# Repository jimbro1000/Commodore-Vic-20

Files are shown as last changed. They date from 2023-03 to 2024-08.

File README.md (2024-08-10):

# Commodore VIC-20 Schematic and PCB for assembly 250403

This repository contains KiCad schematics and "rough" PCB layout for the
cost reduced VIC-20, assembly #250403.

Originally hard forked from <https://github.com/StormTrooper/Commodore-Vic-20>
(this does not appear to be maintained).

The schematic for the Commodore VIC-20 (251027-01 Rev D) was taken from the
schematics on zimmers.net with extra detail from the "Vic-20 friendly computer
technical manual" and converted into KiCad (Version 8).

Additionally includes some KiCad footprints and symbols for the custom components.

## State

The schematics are complete and 95% of the PCB layout is done but it is not
complete. The power supply section of the board is mostly unfinished, and
accurate footprints for the large inductor, power switch and bridge rectifier are
needed.

## Notes

This is a WIP as the documentation and detail on the actual PCB are far from
clear and require some deciphering.

The power management section of the board in particular is unfinished.

The PCB design, while true to the original, is not intended for fabrication.
Instead the board has been reconstructed for the purpose of diagnosing faults
on original Commodore boards. The overall board dimensions are accurate but
the positioning of the different ports are approximations based on the rather
distorted board scans in the technical manual.

## KiCad thumbnail of schematic and pcb

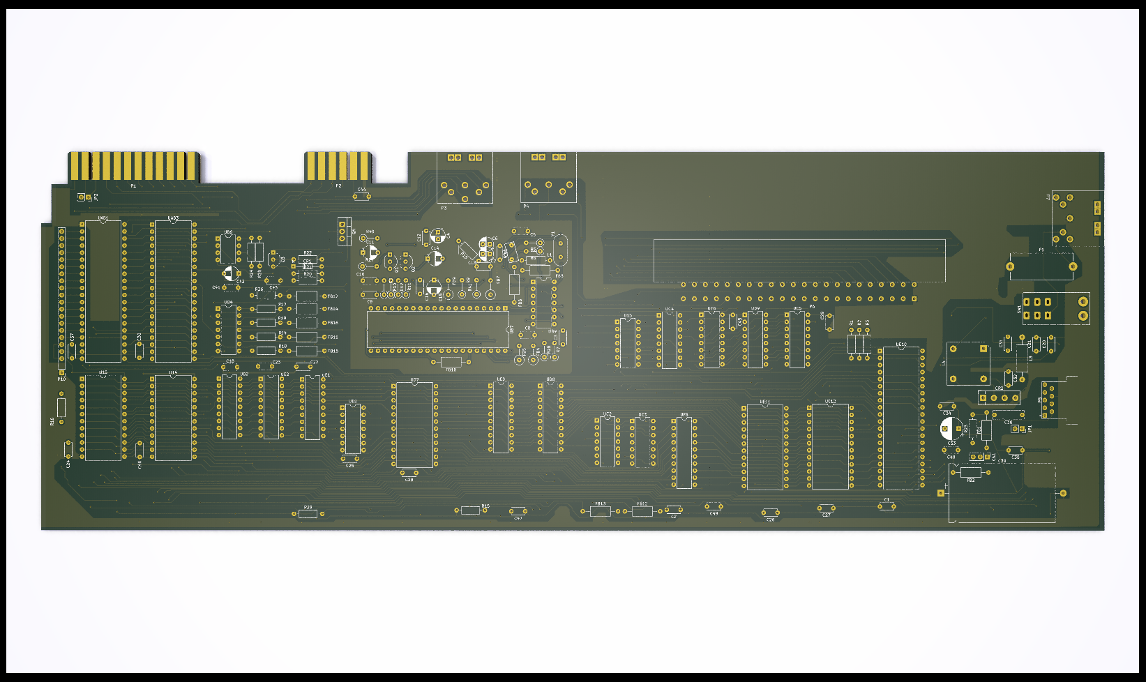
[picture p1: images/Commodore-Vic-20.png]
render of PCB


cad view of schematics

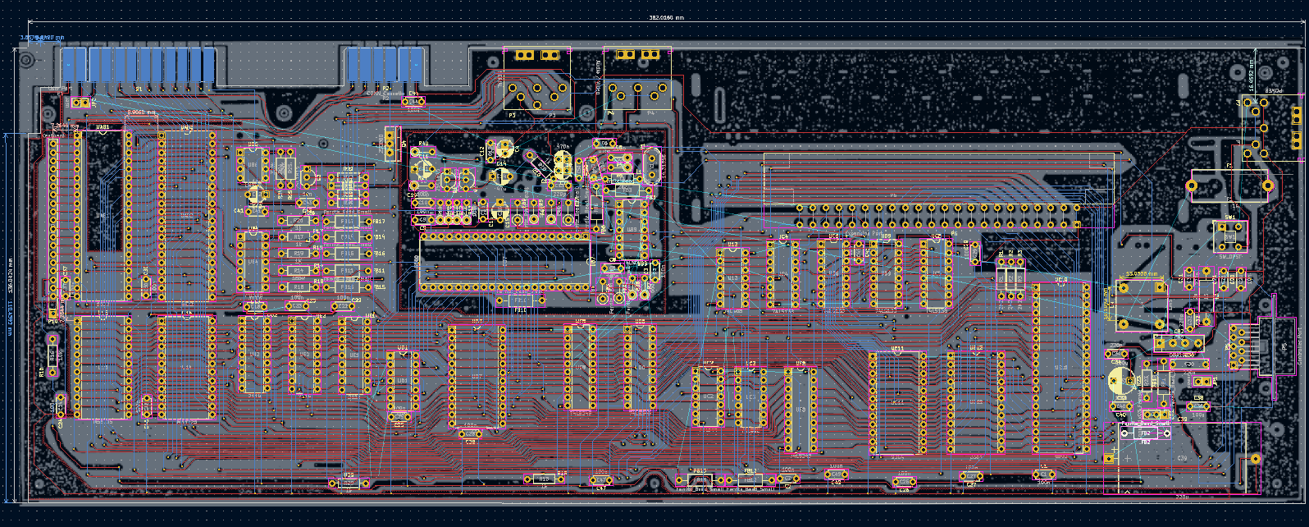
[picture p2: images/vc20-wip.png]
cad view of pcb


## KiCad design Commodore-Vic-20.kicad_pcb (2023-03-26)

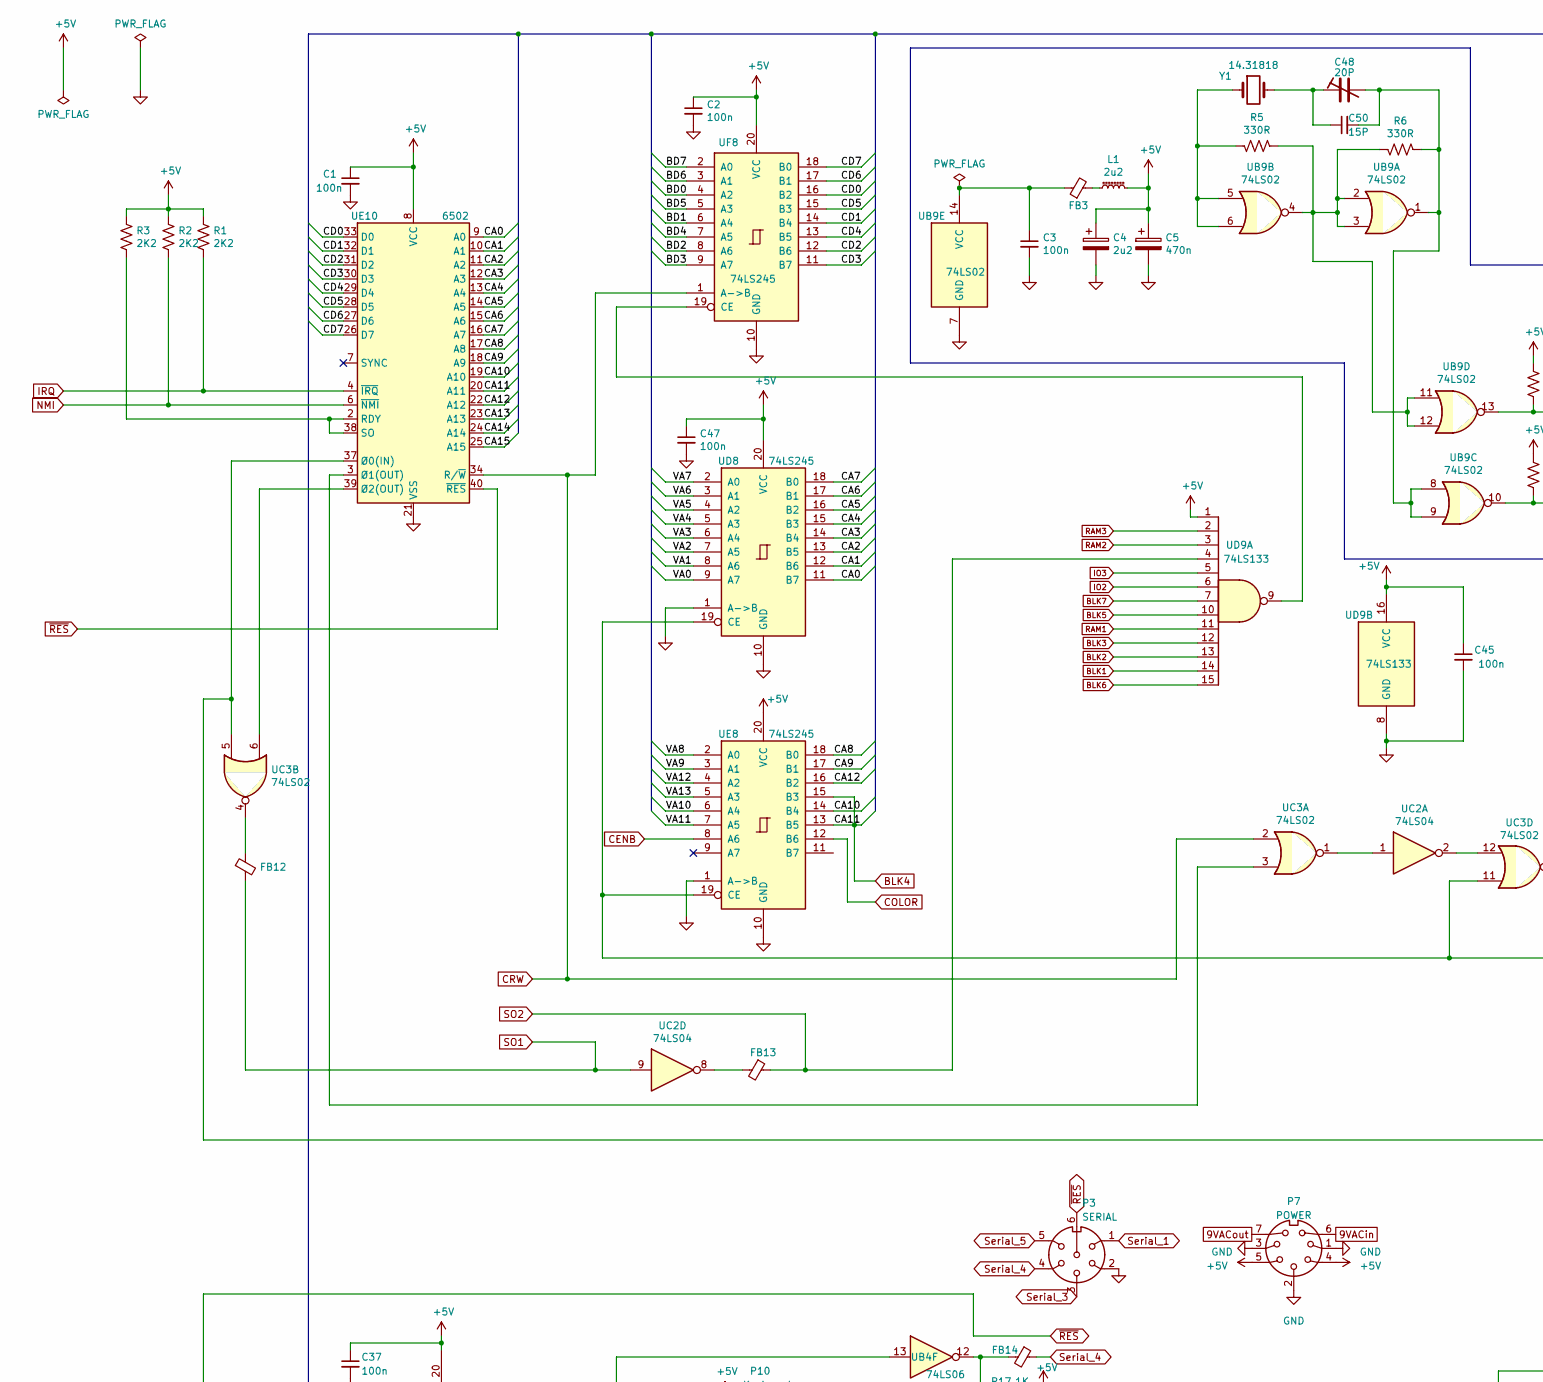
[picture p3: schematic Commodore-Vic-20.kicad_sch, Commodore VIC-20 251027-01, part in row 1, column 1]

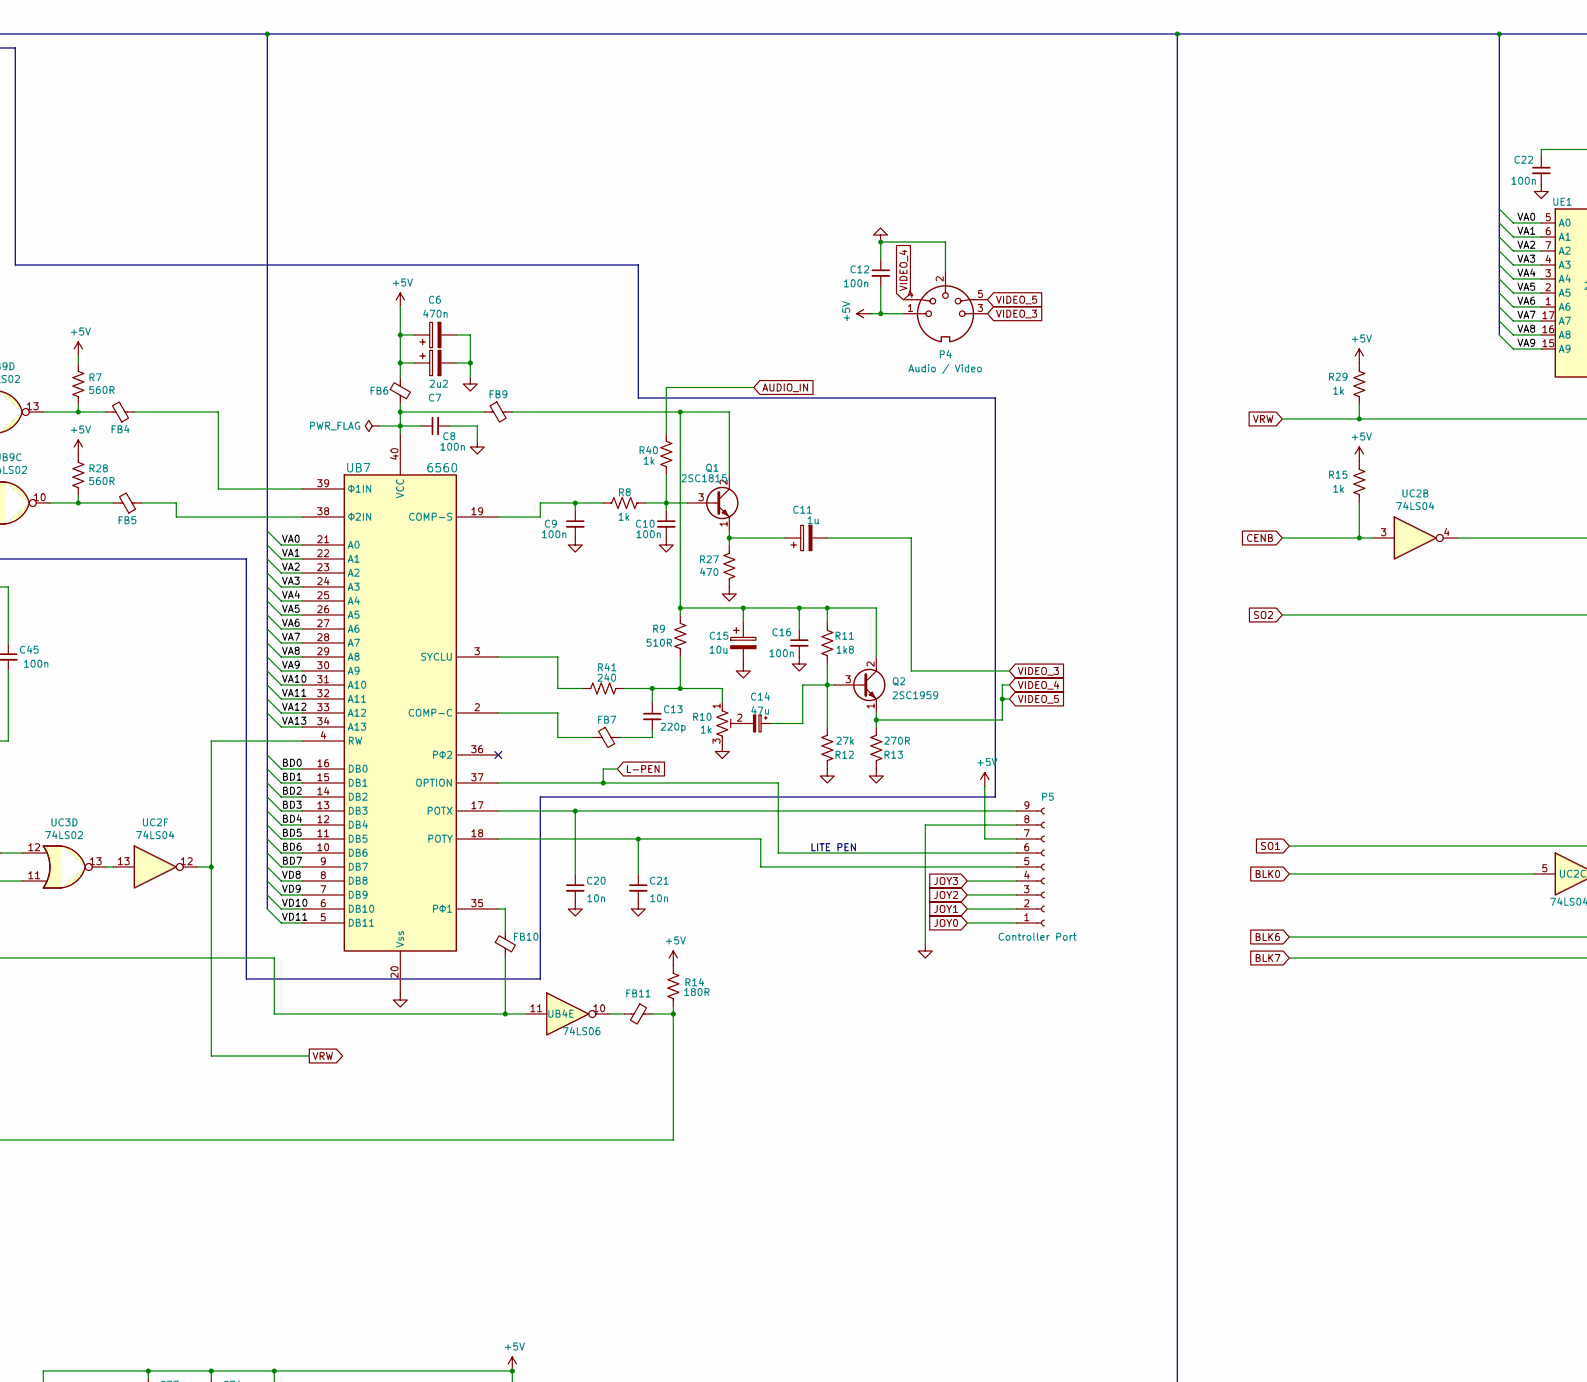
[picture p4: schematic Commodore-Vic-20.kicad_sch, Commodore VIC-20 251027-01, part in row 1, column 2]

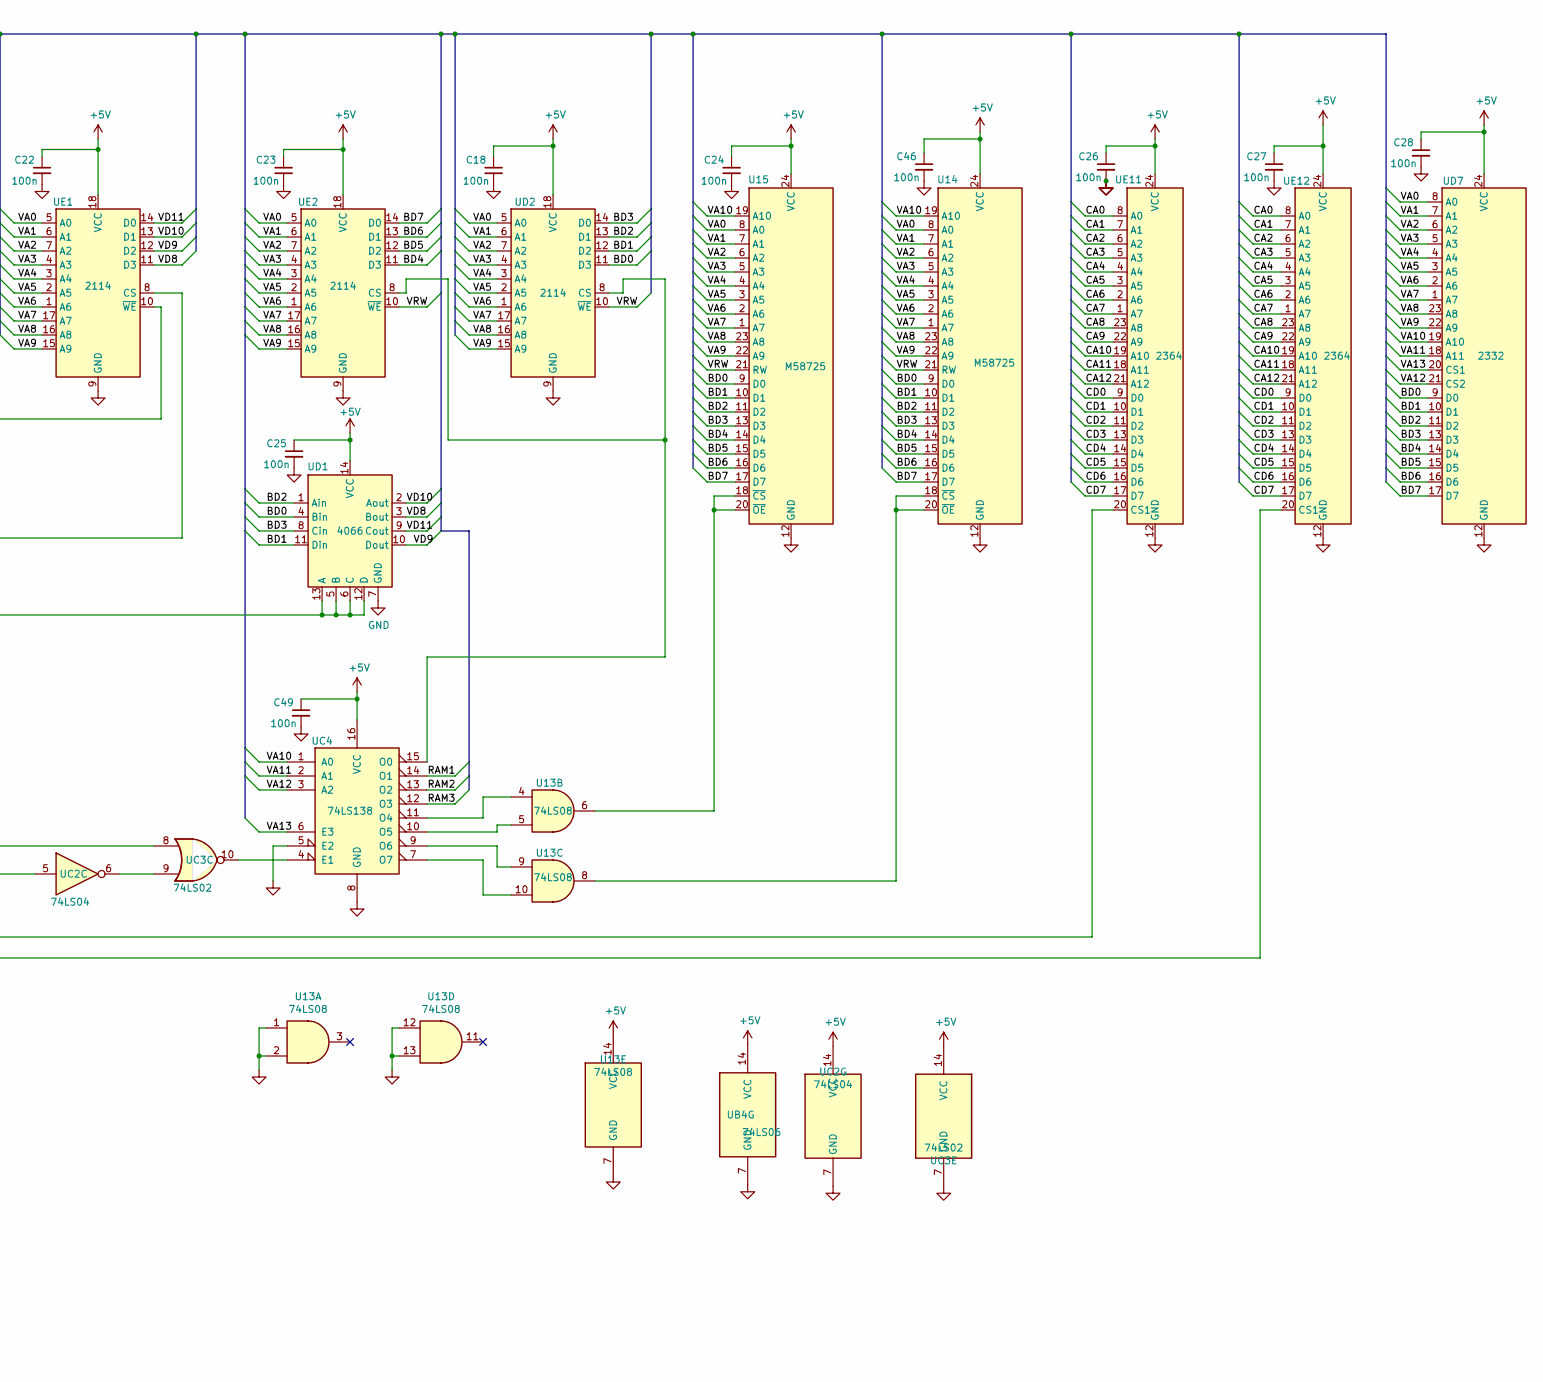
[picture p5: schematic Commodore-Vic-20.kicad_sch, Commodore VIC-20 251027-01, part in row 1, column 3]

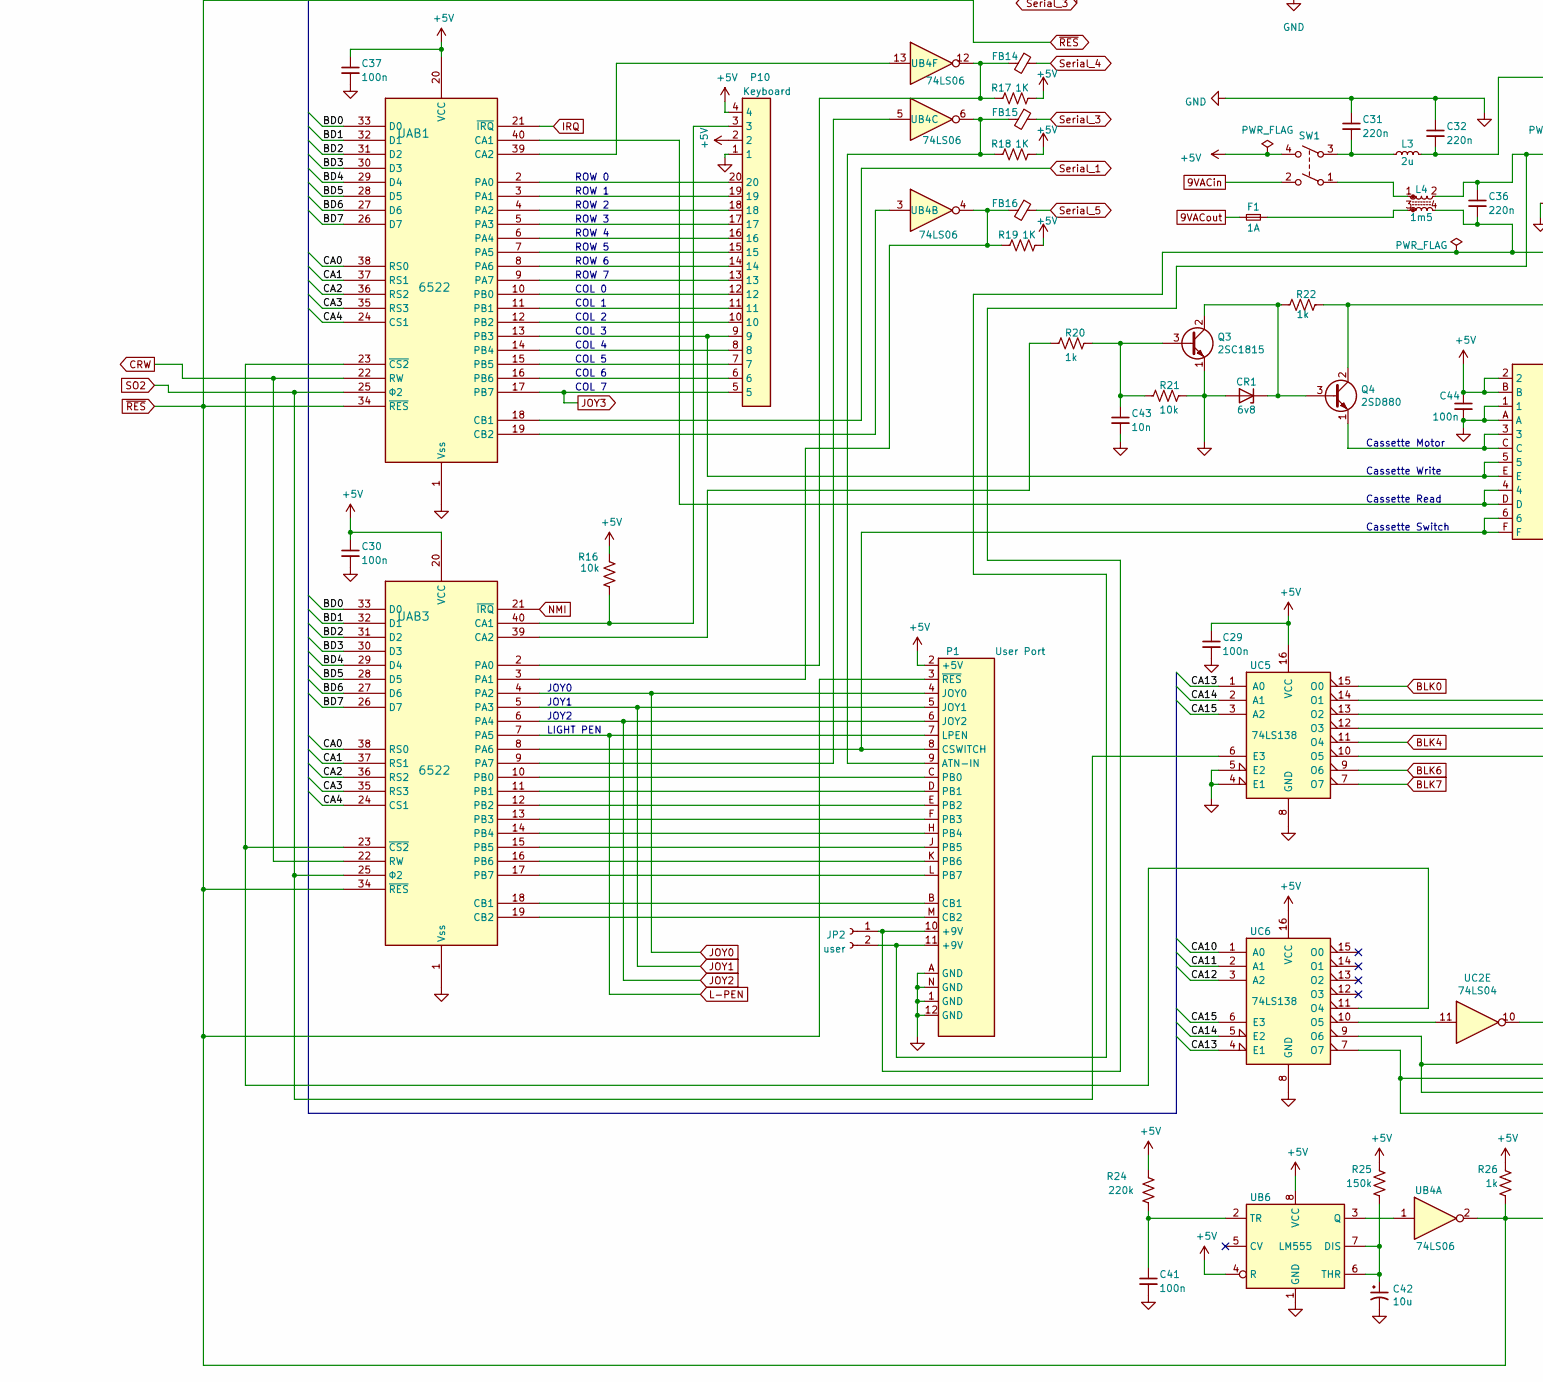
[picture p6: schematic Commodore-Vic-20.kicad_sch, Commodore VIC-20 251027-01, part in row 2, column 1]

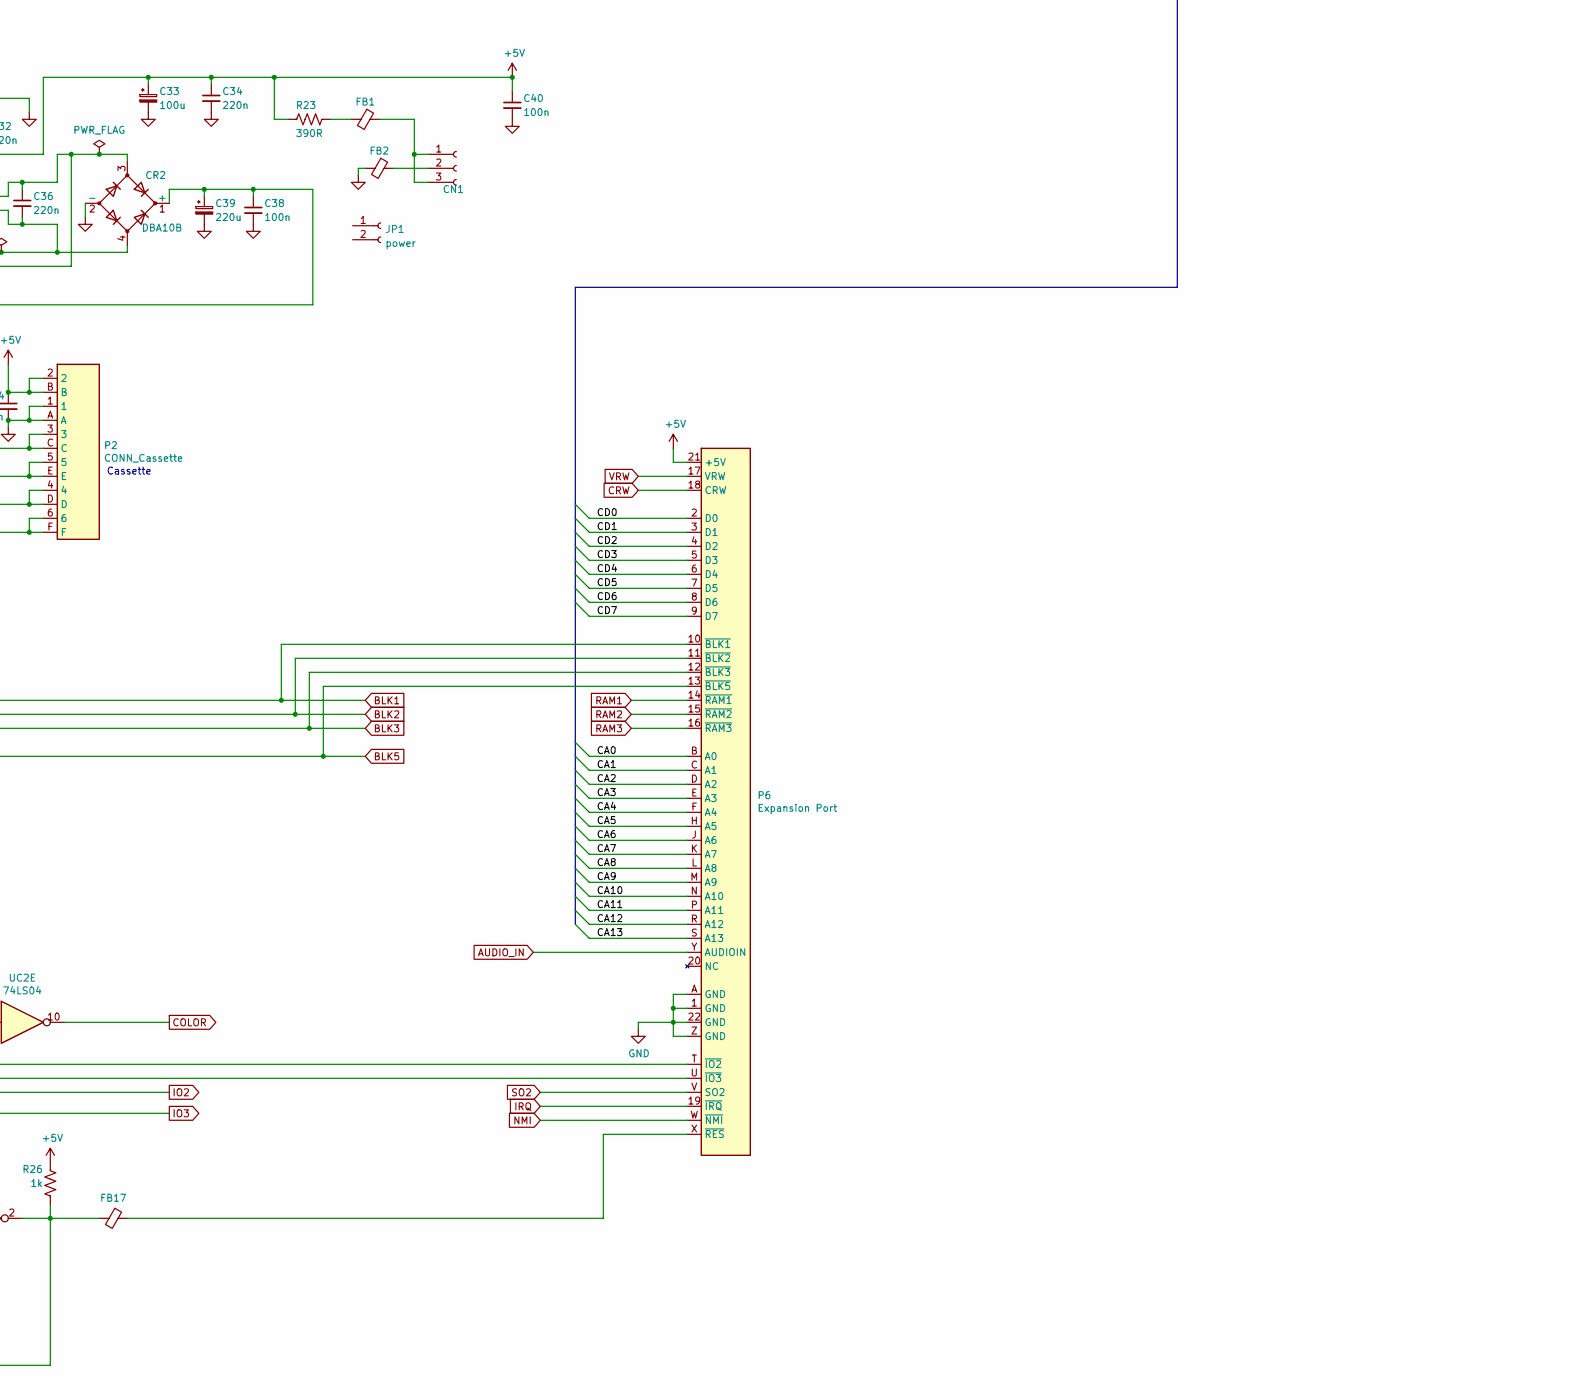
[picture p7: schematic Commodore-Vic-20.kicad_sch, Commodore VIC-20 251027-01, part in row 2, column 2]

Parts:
C1, C2, C3, C8, C9, C10, C12, C16, C18, C22, C23, C24, C25, C26, C27, C28, C29, C30, C37, C38, C40, C41, C44, C45, C46, C47, C49: 100n; C_Disc_D4.7mm_W2.5mm_P5.00mm
C4, C7: 2u2; CP_Radial_D5.0mm_P2.50mm
C5: 470n; C_Disc_D4.7mm_W2.5mm_P5.00mm
C6: 470n; CP_Radial_D5.0mm_P2.50mm
C11: 1u; CP_Radial_D5.0mm_P5.0mm
C13: 220p; C_Disc_D4.7mm_W2.5mm_P5.00mm
C14: 47u; CP_Radial_D5.0mm_P5.0mm
C15, C42: 10u; CP_Radial_D5.0mm_P5.0mm
C20, C21, C43: 10n; C_Disc_D4.7mm_W2.5mm_P5.00mm
C31, C32, C34: 220n; C_Disc_D4.7mm_W2.5mm_P5.00mm
C33: 100u; CP_Radial_D8.0mm_P5.00mm
C36: 220n; C_Rect_L11.0mm_W2.8mm_P10.00mm_MKT
C39: 220u; CP_Axial_L38.0mm_D21.0mm_P44.00mm_Horizontal
C48: 20P; RV_Disc_D7mm_W3.4mm_P5mm
C50: 15P; C_Disc_D4.3mm_W1.9mm_P5.00mm
CN1: Conn_01x03_Female; PinHeader_1x03_P2.54mm_Vertical
CR1: 6v8; D_DO-34_SOD68_P10.16mm_Horizontal
CR2: DBA10B; Diode_Bridge_Vishay_KBPM
F1: 1A; Fuseholder_Cylinder-5x20mm_Stelvio-Kontek_PTF78_Horizontal_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
FB1, FB2, FB3, FB6, FB10, FB11, FB12, FB13, FB14, FB15, FB16, FB17: Ferrite_Bead_Small; L_Axial_L7.0mm_D3.3mm_P12.70mm_Horizontal_Fastron_MICC
FB4, FB5, FB7, FB9: Ferrite_Bead_Small; L_Axial_L7.0mm_D3.3mm_P5.08mm_Vertical_Fastron_MICC
JP1: power; PinSocket_1x02_P2.54mm_Vertical
JP2: user; PinSocket_1x02_P2.54mm_Vertical
L1: 2u2; L_Axial_L6.6mm_D2.7mm_P10.16mm_Horizontal_Vishay_IM-2
L3: 2u; L_Axial_L9.5mm_D4.0mm_P15.24mm_Horizontal_Fastron_SMCC
L4: 1m5; Diode_Bridge_15.2x15.2x6.3mm_P10.9mm
P1: User Port; VC20_USERPORT
P2: CONN_Cassette; VC20_CASSETTE
P3: SERIAL; DIN-6
P4: Audio / Video; DIN-5
P5: Controller Port; DSUB-9_Male_Horizontal_P2.77x2.54mm_EdgePinOffset9.40mm
P6: Expansion Port; VC20_EXPANSIONPORT
P7: POWER; DIN-7
P10: Keyboard; PinHeader_1x21_P2.54mm_Vertical
Q1, Q3: 2SC1815; TO-92_Inline_Wide
Q2: 2SC1959; TO-92_Inline_Wide
Q4: 2SD880; TO-220-3_Vertical
R1, R2, R3: 2K2; R_Axial_DIN0207_L6.3mm_D2.5mm_P10.16mm_Horizontal
R5, R6: 330R; R_Axial_DIN0207_L6.3mm_D2.5mm_P5.08mm_Vertical
R7, R28: 560R; R_Axial_DIN0207_L6.3mm_D2.5mm_P5.08mm_Vertical
R8, R40: 1k; R_Axial_DIN0207_L6.3mm_D2.5mm_P5.08mm_Vertical
R9: 510R; R_Axial_DIN0207_L6.3mm_D2.5mm_P5.08mm_Vertical
R10, R15, R20, R22, R26, R29: 1k; R_Axial_DIN0207_L6.3mm_D2.5mm_P10.16mm_Horizontal
R11: 1k8; R_Axial_DIN0207_L6.3mm_D2.5mm_P5.08mm_Vertical
R12: 27k; R_Axial_DIN0207_L6.3mm_D2.5mm_P5.08mm_Vertical
R13: 270R; R_Axial_DIN0207_L6.3mm_D2.5mm_P5.08mm_Vertical
R14: 180R; R_Axial_DIN0207_L6.3mm_D2.5mm_P10.16mm_Horizontal
R16, R21: 10k; R_Axial_DIN0207_L6.3mm_D2.5mm_P10.16mm_Horizontal
R17, R18, R19: 1K; R_Axial_DIN0207_L6.3mm_D2.5mm_P10.16mm_Horizontal
R23: 390R; R_Axial_DIN0207_L6.3mm_D2.5mm_P10.16mm_Horizontal
R24: 220k; R_Axial_DIN0207_L6.3mm_D2.5mm_P10.16mm_Horizontal
R25: 150k; R_Axial_DIN0207_L6.3mm_D2.5mm_P10.16mm_Horizontal
R27: 470; R_Axial_DIN0207_L6.3mm_D2.5mm_P5.08mm_Vertical
R41: 240; R_Axial_DIN0207_L6.3mm_D2.5mm_P5.08mm_Vertical
SW1: SW_DPST; SW_Push_2P1T_Toggle_CK_PVA1xxH1xxxxxxV2
U13: 74LS08; DIP-14_W7.62mm
U14, U15: M58725; DIP-24_W15.24mm
UAB1, UAB3: 6522; DIP-40_W15.24mm
UB4: 74LS06; DIP-14_W7.62mm
UB6: LM555; DIP-8_W7.62mm
UB7: 6560; DIP-40_W15.24mm
UB9: 74LS02; DIP-14_W7.62mm
UC2: 74LS04; DIP-14_W7.62mm
UC3: 74LS02; DIP-14_W7.62mm
UC4, UC5, UC6: 74LS138; DIP-16_W7.62mm
UD1: 4066; DIP-14_W7.62mm
UD2: 2114; DIP-18_W7.62mm
UD7: 2332; DIP-24_W15.24mm
UD8: 74LS245; DIP-20_W7.62mm
UD9: 74LS133; DIP-16_W7.62mm
UE1, UE2: 2114; DIP-18_W7.62mm
UE8: 74LS245; DIP-20_W7.62mm
UE10: 6502; DIP-40_W15.24mm
UE11, UE12: 2364; DIP-24_W15.24mm
UF8: 74LS245; DIP-20_W7.62mm
Y1: 14.31818; Crystal_HC18-U_Vertical

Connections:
9VACin: P7.6, SW1.2
9VACout: F1.2, P7.7
+5V: C1.1, C2.1, C4.1, C5.1, C6.1, C7.1, C12.2, C18.1, C22.1, C23.1, C24.1, C25.1, C26.1, C27.1, C28.1, C29.1, C30.1, C32.2, C33.1, C34.1, C37.1, C40.1, C44.1, C45.1, C46.1, C47.1, C49.1, FB6.1, L1.2, L3.2, P1.2 (+5V), P2.2, P2.B, P4.1, P5.7, P6.21 (+5V), P7.4, P7.5, P10.2, P10.4, R1.1, R2.1, R3.1, R7.2, R14.1, R15.1, R16.1, R17.1, R18.1, R19.1, R23.1, R24.1, R25.1, R26.1, R28.2, R29.1, SW1.4, U13.14 (VCC), U14.24 (VCC), U15.24 (VCC), UAB1.20 (VCC), UAB3.20 (VCC), UB4.14 (VCC), UB6.4 (R), UB6.8 (VCC), UC2.14 (VCC), UC3.14 (VCC), UC4.16 (VCC), UC5.16 (VCC), UC6.16 (VCC), UD1.14 (VCC), UD2.18 (VCC), UD7.24 (VCC), UD8.20 (VCC), UD9.1, UD9.16 (VCC), UE1.18 (VCC), UE2.18 (VCC), UE8.20 (VCC), UE10.8 (VCC), UE11.24 (VCC), UE12.24 (VCC), UF8.20 (VCC)
/BD0: U14.9 (D0), U15.9 (D0), UAB1.33 (D0), UAB3.33 (D0), UB7.16 (DB0), UD1.4 (Bin), UD2.11 (D3), UD7.9 (D0), UF8.4 (A2)
/BD1: U14.10 (D1), U15.10 (D1), UAB1.32 (D1), UAB3.32 (D1), UB7.15 (DB1), UD1.11 (Din), UD2.12 (D2), UD7.10 (D1), UF8.6 (A4)
/BD2: U14.11 (D2), U15.11 (D2), UAB1.31 (D2), UAB3.31 (D2), UB7.14 (DB2), UD1.1 (Ain), UD2.13 (D1), UD7.11 (D2), UF8.8 (A6)
/BD3: U14.13 (D3), U15.13 (D3), UAB1.30 (D3), UAB3.30 (D3), UB7.13 (DB3), UD1.8 (Cin), UD2.14 (D0), UD7.13 (D3), UF8.9 (A7)
/BD4: U14.14 (D4), U15.14 (D4), UAB1.29 (D4), UAB3.29 (D4), UB7.12 (DB4), UD7.14 (D4), UE2.11 (D3), UF8.7 (A5)
/BD5: U14.15 (D5), U15.15 (D5), UAB1.28 (D5), UAB3.28 (D5), UB7.11 (DB5), UD7.15 (D5), UE2.12 (D2), UF8.5 (A3)
/BD6: U14.16 (D6), U15.16 (D6), UAB1.27 (D6), UAB3.27 (D6), UB7.10 (DB6), UD7.16 (D6), UE2.13 (D1), UF8.3 (A1)
/BD7: U14.17 (D7), U15.17 (D7), UAB1.26 (D7), UAB3.26 (D7), UB7.9 (DB7), UD7.17 (D7), UE2.14 (D0), UF8.2 (A0)
/CA0: P6.B (A0), UAB1.38 (RS0), UAB3.38 (RS0), UD8.11 (B7), UE10.9 (A0), UE11.8 (A0), UE12.8 (A0)
/CA1: P6.C (A1), UAB1.37 (RS1), UAB3.37 (RS1), UD8.12 (B6), UE10.10 (A1), UE11.7 (A1), UE12.7 (A1)
/CA2: P6.D (A2), UAB1.36 (RS2), UAB3.36 (RS2), UD8.13 (B5), UE10.11 (A2), UE11.6 (A2), UE12.6 (A2)
/CA3: P6.E (A3), UAB1.35 (RS3), UAB3.35 (RS3), UD8.14 (B4), UE10.12 (A3), UE11.5 (A3), UE12.5 (A3)
/CA4: P6.F (A4), UAB1.24 (CS1), UAB3.24 (CS1), UD8.15 (B3), UE10.13 (A4), UE11.4 (A4), UE12.4 (A4)
/CA5: P6.H (A5), UD8.16 (B2), UE10.14 (A5), UE11.3 (A5), UE12.3 (A5)
/CA6: P6.J (A6), UD8.17 (B1), UE10.15 (A6), UE11.2 (A6), UE12.2 (A6)
/CA7: P6.K (A7), UD8.18 (B0), UE10.16 (A7), UE11.1 (A7), UE12.1 (A7)
/CA8: P6.L (A8), UE8.18 (B0), UE10.17 (A8), UE11.23 (A8), UE12.23 (A8)
/CA9: P6.M (A9), UE8.17 (B1), UE10.18 (A9), UE11.22 (A9), UE12.22 (A9)
/CA10: P6.N (A10), UC6.1 (A0), UE8.14 (B4), UE10.19 (A10), UE11.19 (A10), UE12.19 (A10)
/CA12: P6.R (A12), UC6.3 (A2), UE8.16 (B2), UE10.22 (A12), UE11.21 (A12), UE12.21 (A12)
/CA13: P6.S (A13), UC5.1 (A0), UC6.4 (E1), UE10.23 (A13)
/CA14: UC5.2 (A1), UC6.5 (E2), UE10.24 (A14)
/CA15: UC5.3 (A2), UC6.6 (E3), UE10.25 (A15)
/CD0: P6.2 (D0), UE10.33 (D0), UE11.9 (D0), UE12.9 (D0), UF8.16 (B2)
/CD1: P6.3 (D1), UE10.32 (D1), UE11.10 (D1), UE12.10 (D1), UF8.14 (B4)
/CD2: P6.4 (D2), UE10.31 (D2), UE11.11 (D2), UE12.11 (D2), UF8.12 (B6)
/CD3: P6.5 (D3), UE10.30 (D3), UE11.13 (D3), UE12.13 (D3), UF8.11 (B7)
/CD4: P6.6 (D4), UE10.29 (D4), UE11.14 (D4), UE12.14 (D4), UF8.13 (B5)
/CD5: P6.7 (D5), UE10.28 (D5), UE11.15 (D5), UE12.15 (D5), UF8.15 (B3)
/CD6: P6.8 (D6), UE10.27 (D6), UE11.16 (D6), UE12.16 (D6), UF8.17 (B1)
/CD7: P6.9 (D7), UE10.26 (D7), UE11.17 (D7), UE12.17 (D7), UF8.18 (B0)
/VA0: U14.8 (A0), U15.8 (A0), UB7.21 (A0), UD2.5 (A0), UD7.8 (A0), UD8.9 (A7), UE1.5 (A0), UE2.5 (A0)
/VA1: U14.7 (A1), U15.7 (A1), UB7.22 (A1), UD2.6 (A1), UD7.7 (A1), UD8.8 (A6), UE1.6 (A1), UE2.6 (A1)
/VA2: U14.6 (A2), U15.6 (A2), UB7.23 (A2), UD2.7 (A2), UD7.6 (A2), UD8.7 (A5), UE1.7 (A2), UE2.7 (A2)
/VA3: U14.5 (A3), U15.5 (A3), UB7.24 (A3), UD2.4 (A3), UD7.5 (A3), UD8.6 (A4), UE1.4 (A3), UE2.4 (A3)
/VA4: U14.4 (A4), U15.4 (A4), UB7.25 (A4), UD2.3 (A4), UD7.4 (A4), UD8.5 (A3), UE1.3 (A4), UE2.3 (A4)
/VA5: U14.3 (A5), U15.3 (A5), UB7.26 (A5), UD2.2 (A5), UD7.3 (A5), UD8.4 (A2), UE1.2 (A5), UE2.2 (A5)
/VA6: U14.2 (A6), U15.2 (A6), UB7.27 (A6), UD2.1 (A6), UD7.2 (A6), UD8.3 (A1), UE1.1 (A6), UE2.1 (A6)
/VA7: U14.1 (A7), U15.1 (A7), UB7.28 (A7), UD2.17 (A7), UD7.1 (A7), UD8.2 (A0), UE1.17 (A7), UE2.17 (A7)
/VA8: U14.23 (A8), U15.23 (A8), UB7.29 (A8), UD2.16 (A8), UD7.23 (A8), UE1.16 (A8), UE2.16 (A8), UE8.2 (A0)
/VA9: U14.22 (A9), U15.22 (A9), UB7.30 (A9), UD2.15 (A9), UD7.22 (A9), UE1.15 (A9), UE2.15 (A9), UE8.3 (A1)
/VA10: U14.19 (A10), U15.19 (A10), UB7.31 (A10), UC4.1 (A0), UD7.19 (A10), UE8.6 (A4)
/VA11: UB7.32 (A11), UC4.2 (A1), UD7.18 (A11), UE8.7 (A5)
/VA12: UB7.33 (A12), UC4.3 (A2), UD7.21 (CS2), UE8.4 (A2)
/VA13: UB7.34 (A13), UC4.6 (E3), UD7.20 (CS1), UE8.5 (A3)
/VD8: UB7.8 (DB8), UD1.3 (Bout), UE1.11 (D3)
/VD9: UB7.7 (DB9), UD1.10 (Dout), UE1.12 (D2)
/VD10: UB7.6 (DB10), UD1.2 (Aout), UE1.13 (D1)
/VD11: UB7.5 (DB11), UD1.9 (Cout), UE1.14 (D0)
AUDIO_IN: P6.Y (AUDIOIN), R40.1
BLK0: UC2.5, UC5.15 (O0)
BLK1: P6.10 (~BLK1), UC5.14 (O1), UD9.14
BLK2: P6.11 (~BLK2), UC5.13 (O2), UD9.13
BLK3: P6.12 (~BLK3), UC5.12 (O3), UD9.12
BLK4: P6.P (A11), UC5.11 (O4), UC6.2 (A1), UE8.13 (B5), UE8.15 (B3), UE10.20 (A11), UE11.18 (A11), UE12.18 (A11)
BLK5: P6.13 (~BLK5), UC5.10 (O5), UD9.10
BLK6: UC5.9 (O6), UD9.15, UE11.20 (CS1)
BLK7: UC5.7 (O7), UD9.7, UE12.20 (CS1)
CENB: R15.2, UC2.3, UE8.8 (A6)
COLOR: UC2.10, UE8.12 (B6)
CRW: P6.18 (CRW), UAB1.22 (RW), UAB3.22 (RW), UC3.2, UE10.34 (R/~W), UF8.1 (A->B)
GND: C1.2, C2.2, C3.2, C4.2, C5.2, C6.2, C7.2, C8.2, C9.2, C10.2, C12.1, C15.2, C16.2, C18.2, C20.2, C21.2, C22.2, C23.2, C24.2, C25.2, C26.2, C27.2, C28.2, C29.2, C30.2, C31.1, C32.1, C33.2, C34.2, C37.2, C38.2, C39.2, C40.2, C41.2, C42.2, C43.2, C44.2, C45.2, C46.2, C47.2, C49.2, CR1.2 (A), CR2.2 (-), FB2.2, P1.1 (GND), P1.12 (GND), P1.A (GND), P1.N (GND), P2.1, P2.A, P3.2, P4.2, P5.8, P6.1 (GND), P6.22 (GND), P6.A (GND), P6.Z (GND), P7.1, P7.2, P7.3, P10.1, Q3.1 (E), R10.3, R12.1, R13.1, R21.2, R27.1, U13.1, U13.2, U13.7 (GND), U13.12, U13.13, U14.12 (GND), U15.12 (GND), UAB1.1 (Vss), UAB3.1 (Vss), UB4.7 (GND), UB6.1 (GND), UB7.20 (Vss), UB9.7 (GND), UC2.7 (GND), UC3.7 (GND), UC4.5 (E2), UC4.8 (GND), UC5.4 (E1), UC5.5 (E2), UC5.8 (GND), UC6.8 (GND), UD1.7 (GND), UD2.9 (GND), UD7.12 (GND), UD8.1 (A->B), UD8.10 (GND), UD9.8 (GND), UE1.9 (GND), UE2.9 (GND), UE8.1 (A->B), UE8.10 (GND), UE10.1 (VSS), UE10.21 (VSS), UE11.12 (GND), UE12.12 (GND), UF8.10 (GND)
IO2: P6.T (~IO2), UC6.9 (O6), UD9.6
IO3: P6.U (~IO3), UC6.7 (O7), UD9.5
IRQ: P6.19 (~IRQ), R1.2, UAB1.21 (~IRQ), UE10.4 (~IRQ)
JOY0: P1.4 (JOY0), P5.1, UAB3.4 (PA2)
JOY1: P1.5 (JOY1), P5.2, UAB3.5 (PA3)
JOY2: P1.6 (JOY2), P5.3, UAB3.6 (PA4)
JOY3: P5.4, P10.5, UAB1.17 (PB7)
L-PEN: P1.7 (LPEN), P5.6, UAB3.7 (PA5), UB7.37 (OPTION)
NMI: P6.W (~NMI), R2.2, UAB3.21 (~IRQ), UE10.6 (~NMI)
unnamed: C8.1, FB6.2, FB9.1, UB7.40 (VCC)
unnamed: C36.1, CR2.3, JP2.1, L4.2, P1.10 (+9V)
unnamed: C36.2, CR2.4, JP2.2, L4.4, P1.11 (+9V)
unnamed: C3.1, FB3.1, UB9.14 (VCC)
unnamed: C13.1, R9.2, R10.1, R41.2
unnamed: C13.2, FB7.2
unnamed: C14.2, R10.2
unnamed: C31.2, L3.1, SW1.3
unnamed: C48.1, C50.1, Y1.2
unnamed: C48.2, C50.2, R6.2, UB9.1, UB9.8, UB9.9
unnamed: CN1.1, CN1.3, FB1.1
unnamed: CN1.2, FB2.1
unnamed: CR1.1 (K), Q3.2 (C), Q4.3 (B), R22.1
unnamed: C38.1, C39.1, CR2.1 (+), Q4.2 (C), R22.2
unnamed: F1.1, L4.3
unnamed: FB1.2, R23.2
unnamed: FB3.2, L1.1
unnamed: FB4.2, R7.1, UB9.13
unnamed: FB5.2, R28.1, UB9.10
unnamed: FB11.2, UB4.10
unnamed: FB12.1, UC3.4
unnamed: FB13.2, UC2.8
unnamed: L4.1, SW1.1
unnamed: FB15.2, P1.9 (ATN-IN), R18.2, UB4.6
unnamed: P1.B (CB1), UAB3.18 (CB1)
unnamed: P1.M (CB2), UAB3.19 (CB2)
unnamed: P1.8 (CSWITCH), P2.6, P2.F, UAB3.8 (PA6)
unnamed: P1.C (PB0), UAB3.10 (PB0)
unnamed: P1.D (PB1), UAB3.11 (PB1)
unnamed: P1.E (PB2), UAB3.12 (PB2)
unnamed: P1.F (PB3), UAB3.13 (PB3)
unnamed: P1.H (PB4), UAB3.14 (PB4)
unnamed: P1.J (PB5), UAB3.15 (PB5)
unnamed: P1.K (PB6), UAB3.16 (PB6)
unnamed: P1.L (PB7), UAB3.17 (PB7)
unnamed: C21.1, P5.5, UB7.18 (POTY)
unnamed: C20.1, P5.9, UB7.17 (POTX)
unnamed: FB17.1, P6.X (~RES)
unnamed: C10.1, Q1.3 (B), R8.2, R40.2
unnamed: C15.1, C16.1, FB9.2, Q1.2 (C), Q2.2 (C), R9.1, R11.1
unnamed: C11.1, Q1.1 (E), R27.2
unnamed: C14.1, Q2.3 (B), R11.2, R12.2
unnamed: C43.1, Q3.3 (B), R20.2, R21.1
unnamed: P2.3, P2.C, Q4.1 (E)
unnamed: R5.1, UB9.5, UB9.6, Y1.1
unnamed: R5.2, R6.1, UB9.2, UB9.3, UB9.4, UB9.11, UB9.12
unnamed: U13.8, U14.18 (~CS), U14.20 (~OE)
unnamed: U13.6, U15.18 (~CS), U15.20 (~OE)
unnamed: P2.4, P2.D, UAB1.40 (CA1)
unnamed: UAB1.39 (CA2), UB4.13
unnamed: UAB1.19 (CB2), UB4.3
unnamed: P10.20, UAB1.2 (PA0)
unnamed: P10.19, UAB1.3 (PA1)
unnamed: P10.18, UAB1.4 (PA2)
unnamed: P10.17, UAB1.5 (PA3)
unnamed: P10.16, UAB1.6 (PA4)
unnamed: P10.15, UAB1.7 (PA5)
unnamed: P10.14, UAB1.8 (PA6)
unnamed: P10.13, UAB1.9 (PA7)
unnamed: P10.12, UAB1.10 (PB0)
unnamed: P10.11, UAB1.11 (PB1)
unnamed: P10.10, UAB1.12 (PB2)
unnamed: P2.5, P2.E, P10.9, UAB1.13 (PB3)
unnamed: P10.8, UAB1.14 (PB4)
unnamed: P10.7, UAB1.15 (PB5)
unnamed: P10.6, UAB1.16 (PB6)
unnamed: UAB1.23 (~CS2), UAB3.23 (~CS2), UC6.11 (O4)
unnamed: P10.3, R16.2, UAB3.40 (CA1)
unnamed: R20.1, UAB3.39 (CA2)
unnamed: FB14.2, R17.2, UAB3.2 (PA0), UB4.12
unnamed: FB16.2, R19.2, UAB3.3 (PA1), UB4.4
unnamed: UAB3.9 (PA7), UB4.5
unnamed: C42.1, R25.2, UB6.6 (THR), UB6.7 (DIS)
unnamed: UB4.1, UB6.3 (Q)
unnamed: C41.1, R24.2, UB6.2 (TR)
unnamed: FB7.1, UB7.2 (COMP-C)
unnamed: C9.1, R8.1, UB7.19 (COMP-S)
unnamed: FB10.1, UB7.35 (PФ1)
unnamed: R41.1, UB7.3 (SYCLU)
unnamed: FB4.1, UB7.39 (Ф1IN)
unnamed: FB5.1, UB7.38 (Ф2IN)
unnamed: UC2.1, UC3.1
unnamed: UC2.2, UC3.12
unnamed: UC2.6, UC3.9
unnamed: UC2.13, UC3.13
unnamed: UC3.10, UC4.4 (E1)
unnamed: UC4.15 (O0), UD2.8 (CS), UE2.8 (CS)
unnamed: U13.4, UC4.11 (O4)
unnamed: U13.5, UC4.10 (O5)
unnamed: U13.9, UC4.9 (O6)
unnamed: U13.10, UC4.7 (O7)
unnamed: UC2.11, UC6.10 (O5)
unnamed: FB10.2, UB4.11, UC3.11, UD8.19 (CE), UE8.19 (CE)
unnamed: UC2.4, UE1.8 (CS)
unnamed: R3.2, UE10.2 (RDY), UE10.38 (SO)
unnamed: FB11.1, R14.2, UC3.5, UE10.37 (Ø0(IN))
unnamed: UC3.3, UE10.3 (Ø1(OUT))
unnamed: UC3.6, UE10.39 (Ø2(OUT))
unnamed: UD9.9, UF8.19 (CE)
RAM1: P6.14 (~RAM1), UC4.14 (O1), UD9.11
RAM2: P6.15 (~RAM2), UC4.13 (O2), UD9.3
RAM3: P6.16 (~RAM3), UC4.12 (O3), UD9.2
SO1: FB12.2, UC2.9, UC3.8
SO2: FB13.1, P6.V (SO2), UAB1.25 (Φ2), UAB3.25 (Φ2), UC5.6 (E3), UD1.5 (B), UD1.6 (C), UD1.12 (D), UD1.13 (A), UD9.4
Serial_1: P3.1, UAB1.18 (CB1)
Serial_3: FB15.1, P3.3
Serial_4: FB14.1, P3.4
Serial_5: FB16.1, P3.5
VIDEO_3: C11.2, P4.3
VIDEO_4: P4.4, P4.5, Q2.1 (E), R13.2
VRW: P6.17 (VRW), R29.2, U14.21 (RW), U15.21 (RW), UB7.4 (RW), UC2.12, UD2.10 (~WE), UE1.10 (~WE), UE2.10 (~WE)
~RES: FB17.2, P1.3 (~RES), P3.6, R26.2, UAB1.34 (~RES), UAB3.34 (~RES), UB4.2, UE10.40 (~RES)

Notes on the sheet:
ROW 1
ROW 3
JOY0
Cassette Read
Cassette Motor
COL 0
COL 2
ROW 0
JOY2
Cassette Write
ROW 7
JOY1
ROW 5
ROW 6
LITE PEN
LIGHT PEN
COL 4
Cassette
ROW 2
COL 6
COL 3
COL 7
COL 5
Cassette Switch
COL 1
ROW 4

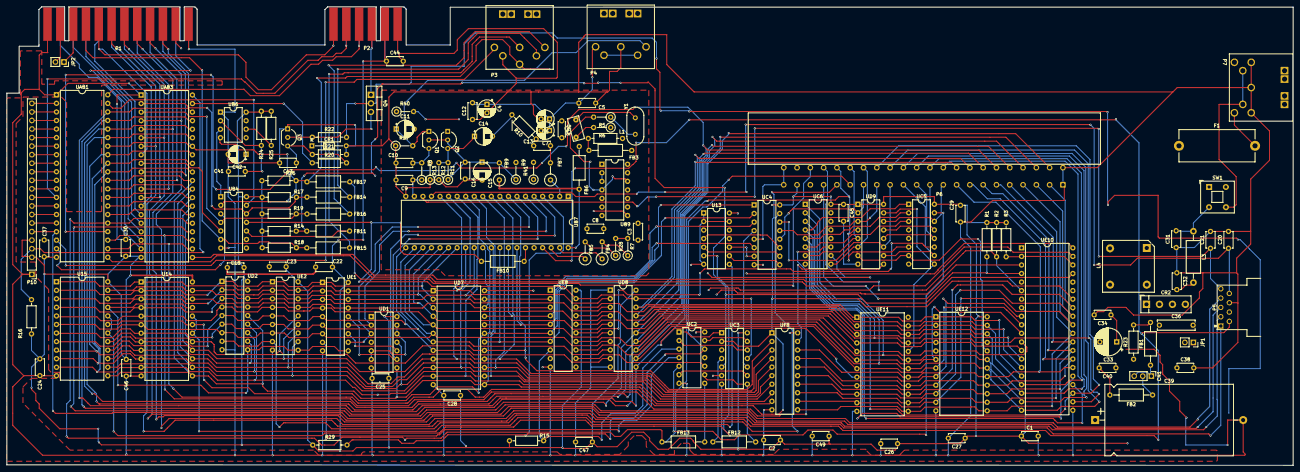
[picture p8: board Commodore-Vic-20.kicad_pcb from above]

Board: 2 copper layers, 382.1 x 136.2 mm, 142 parts (0 on the bottom side), 186 nets.

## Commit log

2023-03-15 initial board design
    [Commodore-Vic-20.kicad_pcb, Commodore-Vic-20.kicad_sch]
2023-03-16 replicate original board
    [Commodore-Vic-20.kicad_pcb, Commodore-Vic-20.kicad_sch]
2023-03-16 fix inductor
    [Commodore-Vic-20.kicad_pcb, Commodore-Vic-20.kicad_sch]
2023-03-16 dimension inductor
    [Commodore-Vic-20.kicad_pcb, Commodore-Vic-20.kicad_sch]
2023-03-17 develop rear of board
    [Commodore-Vic-20.kicad_pcb, Commodore-Vic-20.kicad_sch]
2023-03-18 more wiring
    [Commodore-Vic-20.kicad_pcb, Commodore-Vic-20.kicad_sch]
2023-03-19 refresh project details
    [Commodore-Vic-20.kicad_pcb, Commodore-Vic-20.kicad_sch]
2023-03-19 add pdb render
    [Commodore-Vic-20.kicad_pcb]
2023-03-26 improve trace names
    [Commodore-Vic-20.kicad_pcb, Commodore-Vic-20.kicad_sch]
2023-04-02 progress traces
    [Commodore-Vic-20.kicad_sch]
2024-08-10 resolve power circuit
    [Commodore-Vic-20.kicad_sch]
2024-08-10 improve pcb
2024-08-10 colour code buses in schematics
    [Commodore-Vic-20.kicad_sch]
